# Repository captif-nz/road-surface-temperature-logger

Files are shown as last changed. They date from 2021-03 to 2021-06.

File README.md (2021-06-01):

# Road surface temperature logger

The road surface temperature logger has been designed as a low-cost unit to support various road surfacing trials. The logger utilises a Pycom microcontroller with screw terminals for upto four DS18B20 temperature probes. Inputs are also provided for a rain gauge, anemometer and light sensor, if needed.

The Pycom microcontroller provides for easier development of the onboard software (in Python), along with built-in cellular and/or LoRa/SigFox connectivity. 

## Parts list

### Custom parts (see sections below)

- PCB
- Enclosure mount

### PCB components
- [Pycom FiPy](https://pycom.io/product/fipy/) or [LoPy4](https://pycom.io/product/lopy4) (no cellular)
- [Lithium battery solar charge controller](https://www.adafruit.com/product/390)
- 2x [JST-PH socket](https://nz.rs-online.com/web/p/products/8201422/)
- 2x [Tactile switch](https://nz.rs-online.com/web/p/products/4791413/)
- 2x [100k Ohm resistor](https://nz.rs-online.com/web/p/through-hole-fixed-resistors/7550704/)
- 1x [4.7k Ohm resistor](https://nz.rs-online.com/web/p/through-hole-fixed-resistors/7077726/)
- 1x [220 Ohm resistor](https://nz.rs-online.com/web/p/through-hole-fixed-resistors/7077612/)
- 2x [14-way PCB socket (single row, 2.54mm)](https://nz.rs-online.com/web/p/products/1981500/)
- 1x [6-way PCB socket (single row, 2.54mm)](https://nz.rs-online.com/web/p/pcb-sockets/1981494)
- 3x [2-way PCB header (single row, 2.54mm)](https://nz.rs-online.com/web/p/pcb-headers/1802111/)
- 3x [6-way terminal block (2.54mm)](https://nz.rs-online.com/web/p/products/1918717/)
- 1x [2-way terminal block (2.54mm)](https://nz.rs-online.com/web/p/pcb-terminal-blocks/1919055/)

### Logger hardware
- [Enclosure with polycarbonate cover](https://www.digikey.co.nz/product-detail/en/bud-industries/PN-1325-CMB/377-1894-ND/2674158)
- [2.5W solar panel](https://www.seeedstudio.com/2-5W-Solar-Panel-116X160.html)
- 3.7V lithium battery (~13.8 Ah with built-in protection)
- [DS18B20 temperature probes](https://nz.rs-online.com/web/p/temperature-humidity-sensor-ics/1901709/)
- 3-core sensor wire (temperature probe extension)
- [6.4mm heat shrink](https://nz.rs-online.com/web/p/heat-shrink-cold-shrink-sleeves/0397821) (temperature probe encapsulation)
- [*DAVIS rain collector #6466M*](https://scientificsales.co.nz/davis-6466m-aerocone-rain-collector-pole-mount-0.2mm/) (optional)
- [*DAVIS anemometer #6410*](https://scientificsales.co.nz/davis-6410-anemometer-for-vantage-pro/) (optional)

### Programming hardware
- [PyCom Expansion board](https://pycom.io/product/expansion-board-3-0/) OR
- [Serial programmer](https://nz.rs-online.com/web/p/communication-wireless-development-tools/1346453/)

### Mounting system
- Pole and socket
- U-bolts

## PCB

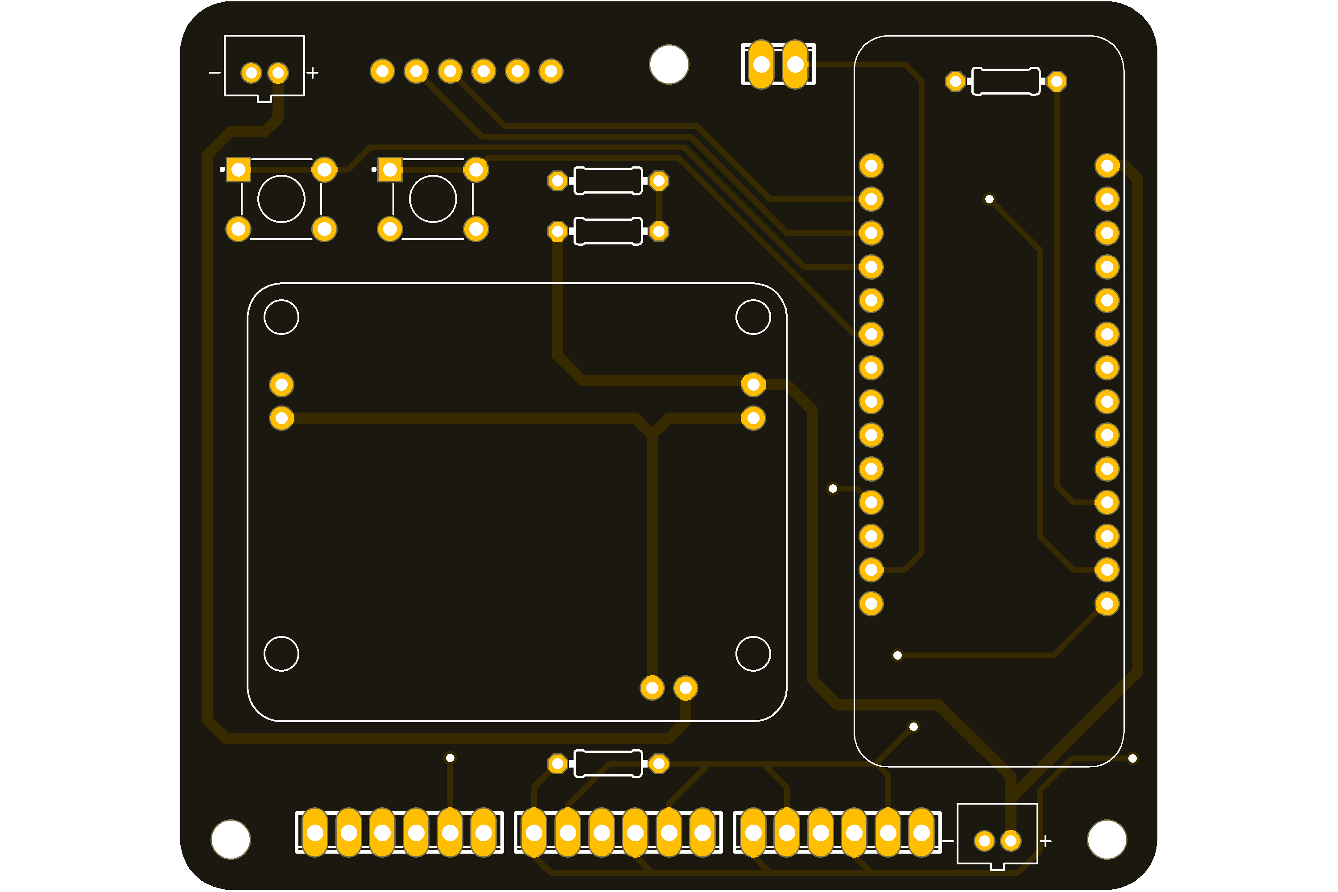
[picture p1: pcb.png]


The printed circuit board manufacturing files can be found in [assembley_files.zip](assembly_files.zip). There are a number of low-cost options available for getting these manufactured.

## Enclosure mount

Models of the enclosure mounting plate and solar panel frame can be found in [enclosure_mount.zip](enclosure_mount.zip). These are designed for the enclosure, solar panel and PCB listed in the parts section above. The enclosure mount parts should be 3D printed out of ABS plastic.

## Licence

MIT

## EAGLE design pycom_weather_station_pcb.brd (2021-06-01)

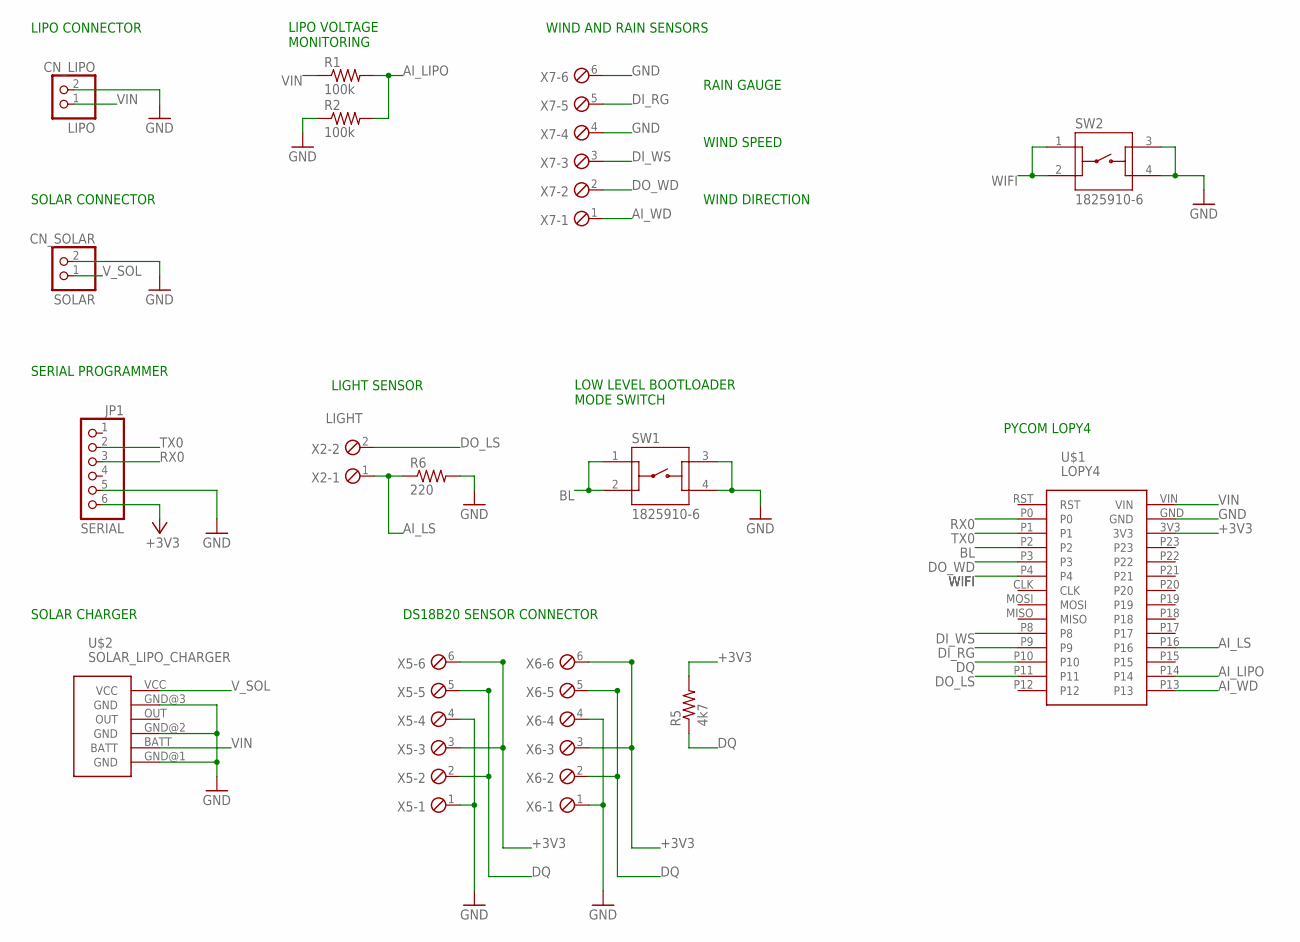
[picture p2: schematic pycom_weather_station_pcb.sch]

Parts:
CN_LIPO: LIPO; JST-PH-2-THM
CN_SOLAR: SOLAR; JST-PH-2-THM
JP1: SERIAL; 1X06-CLEANBIG
R1, R2: 100k; 0204/7
R5: 4k7; 0204/7
R6: 220; 0204/7
SW1, SW2: 1825910-6; SW_1825910-6-4
U$1: LOPY4
U$2: SOLAR_LIPO_CHARGER
X2: LIGHT; 2POL254
X5, X6, X7: MPT6; 6POL254

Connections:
+3V3: JP1.6, R5.2, U$1.3V3, X5.3, X5.6, X6.3, X6.6
AI_LIPO: R1.2, R2.2, U$1.P14
AI_LS: R6.1, U$1.P16, X2.1
AI_WD: U$1.P13, X7.1
BL: SW1.1, SW1.2, U$1.P2
DI_RG: U$1.P9, X7.5
DI_WS: U$1.P8, X7.3
DO_LS: U$1.P11, X2.2
DO_WD: U$1.P3, X7.2
DQ: R5.1, U$1.P10, X5.2, X5.5, X6.2, X6.5
GND: CN_LIPO.2 (1), CN_SOLAR.2 (1), JP1.5, R2.1, R6.2, SW1.3, SW1.4, SW2.3, SW2.4, U$1.GND, U$2.GND@1 (GND), U$2.GND@2 (GND), U$2.GND@3 (GND), X5.1, X5.4, X6.1, X6.4, X7.4, X7.6
RX0: JP1.3, U$1.P0
TX0: JP1.2, U$1.P1
VIN: CN_LIPO.1 (2), R1.1, U$1.VIN, U$2.BATT
V_SOL: CN_SOLAR.1 (2), U$2.VCC
WIFI: SW2.1, SW2.2, U$1.P4

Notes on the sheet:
LIPO CONNECTOR
SOLAR CONNECTOR
SERIAL PROGRAMMER
SOLAR CHARGER
LIPO VOLTAGE MONITORING
DS18B20 SENSOR CONNECTOR
LIGHT SENSOR
WIND DIRECTION
WIND SPEED
RAIN GAUGE
WIND AND RAIN SENSORS
LOW LEVEL BOOTLOADER MODE SWITCH
PYCOM LOPY4

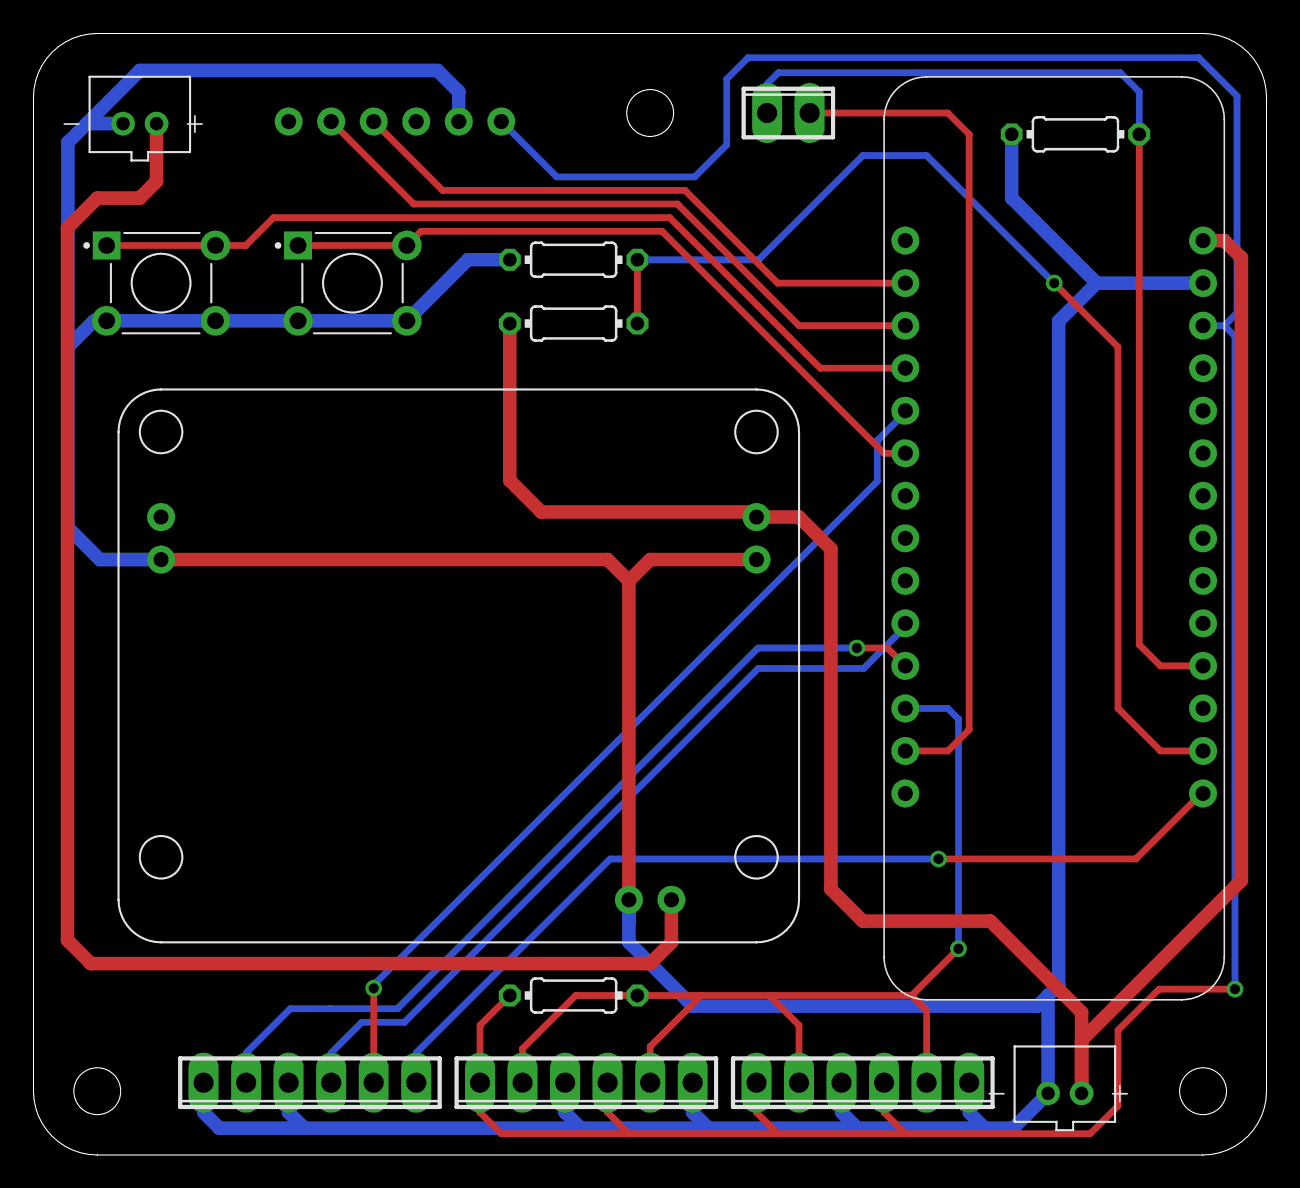
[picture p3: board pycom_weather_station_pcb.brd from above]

Board: 2 copper layers, 73.6 x 67.0 mm, 15 parts (0 on the bottom side), 16 nets.

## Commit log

2021-03-12 Add pcb image
2021-06-01 add enclosure stl models
2021-06-01 update pcb design
    [pycom_weather_station_pcb.brd]
2021-06-01 add solar panel frame
